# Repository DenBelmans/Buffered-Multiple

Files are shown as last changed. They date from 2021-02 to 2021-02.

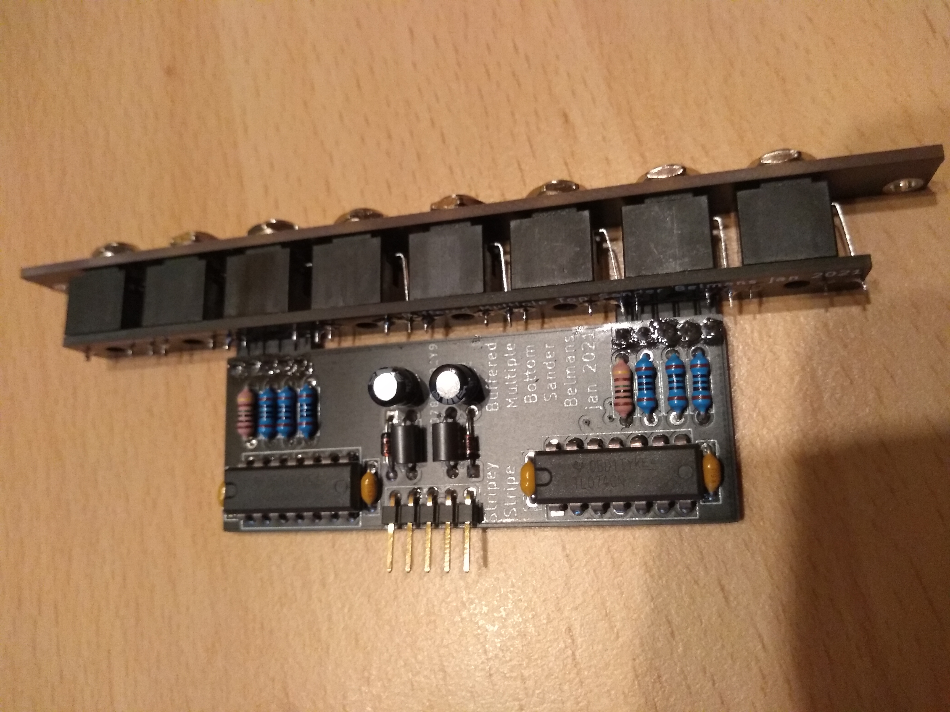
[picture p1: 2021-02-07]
mult2.jpg

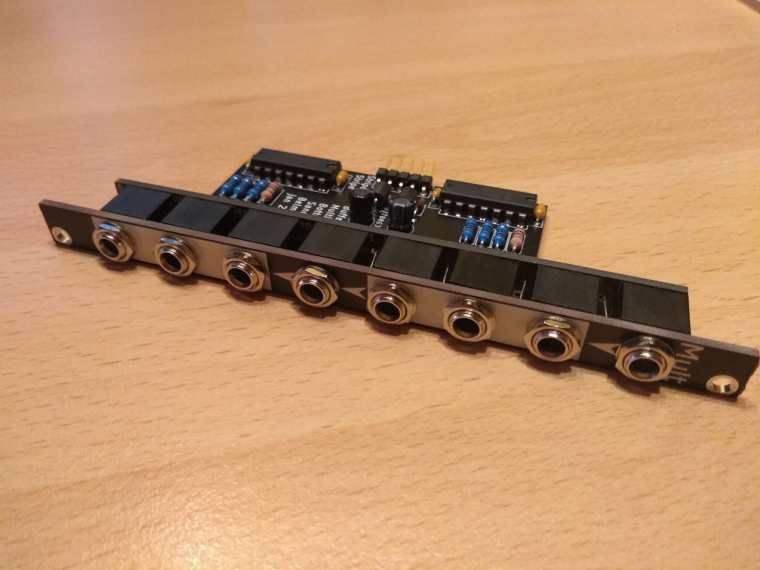
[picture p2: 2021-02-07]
mult1.jpg

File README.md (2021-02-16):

# Buffered-Multiple
A 2HP buffered Multiple in Eurorack format. 2x3 or 1x6 configurations possible.

***** Build Instructions *****

1) Start off by placing the right-angled headers in the PCB that will house the thonkiconns. Place their straight leads through the holes and cut them off flush with the PCB. Take them out again and cut them off a little more so that you can solder them flush to the board without any stubs sticking out. Solder them.
2) Place all thonkiconns on the board, place the front panel on and fasten the nuts. Then flip over the assembly and solder the jacks in place.
3) Take the smaller pcb and solder all resistors, diodes, capacitors and ferrite beads. Make sure you solder the electrolytic capacitors as flush as possible or if you are using caps that are taller than 5mm solder them with their bodies flat on the PCB.
4) Solder the IC's directly to the board. There is no room for sockets!
5) Place the second board on the right angled connectors so that the second board tilted a bit down (towards the side that has no components. Make sure you stay within the 2HP width! Then solder it in place.
6) Solder the 1x5 right angled power connector. I left room for a 2x5 connector but these were a little tall. I used the rowo furthest away from the edge. Solder it so that, when connected, the power connector is within the 2HP width.

That should be all. If you encounter any problems or have questions, feel free to contact me via e-mail: belmansander@gmail.com

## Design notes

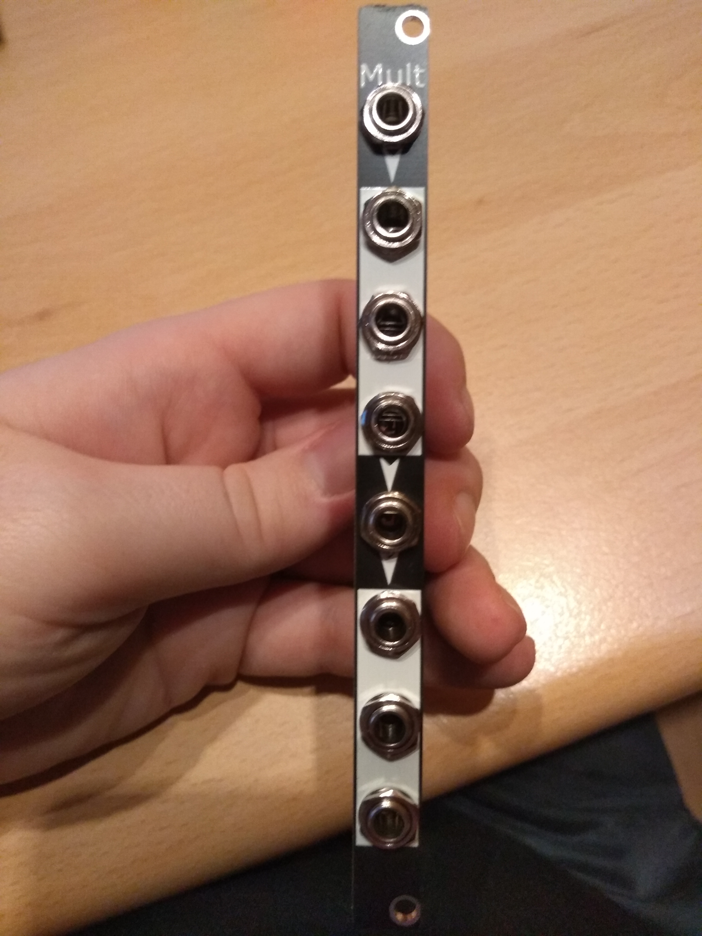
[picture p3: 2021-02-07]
mult3.jpg

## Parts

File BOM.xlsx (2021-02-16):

Buffered Mult BOM
Part | Amount | Mouser number
Thonkiconn jack | 8 |  | Not available at Mouser
1x5 right-angled header | 3 | 649-1012937990501BLF
100 Ohm 1/4W THT resistor | 6 | 603-MFR-25FTF52-100R | 6.3mm length or less
10MOhm 1/4W THT resistor | 2 | 603-HHV-25FR-52-10M | 6.3mm length or less
TL074 op amp | 2 | 595-TL074CN | DIP14
100nF capacitor | 4 | 80-C410C104M5U | any low profile 5mm pitch 100nF cap will do
1N5817 Schottky diode THT | 2 | 583-1N5817-T | 1N4148 diodes work too, though this will result in a maximum output voltage of +/-11V
ferrite bead | 2 | 81-BL01RN1A1F1J | Any ferrite bead. If you don't have these, short both sides
10uF capacitor, low profile | 2 | 667-ECE-A1VKS100I | If you don't have low profile caps, lay flat on the board.

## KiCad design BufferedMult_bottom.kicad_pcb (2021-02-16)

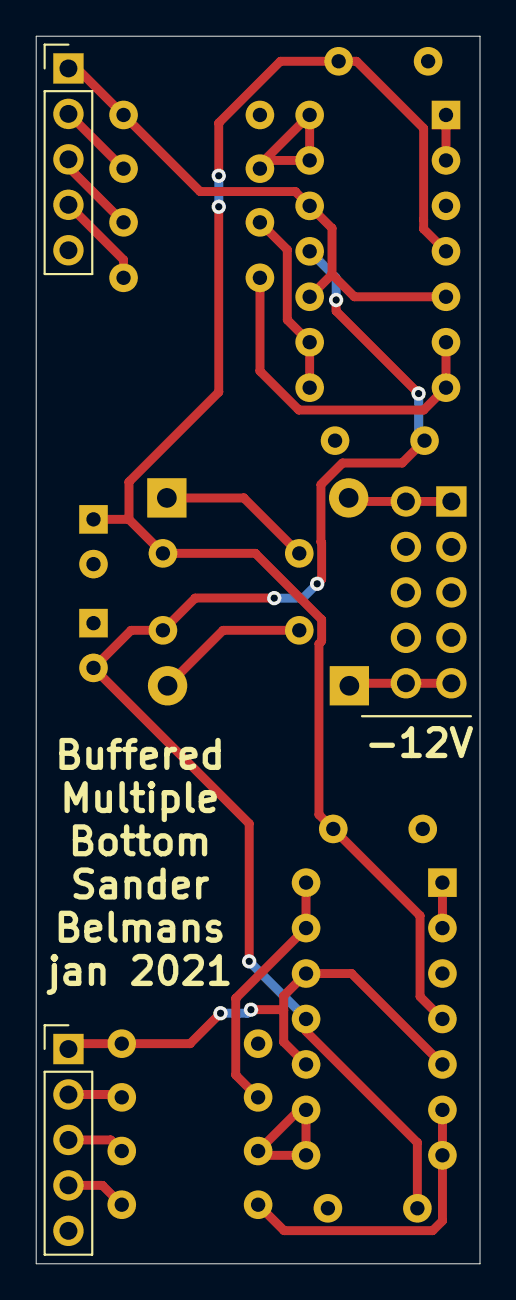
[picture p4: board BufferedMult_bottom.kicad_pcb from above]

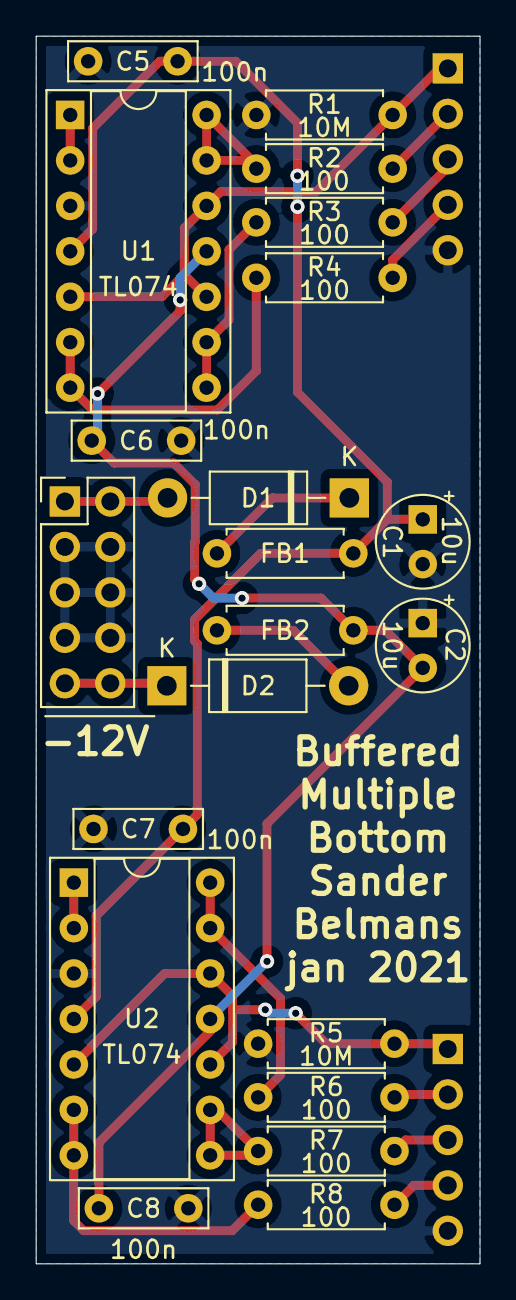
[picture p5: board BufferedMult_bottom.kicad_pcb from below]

Board: 2 copper layers, 24.8 x 68.6 mm, 23 parts (21 on the bottom side), 23 nets.

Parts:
C1, C2: 10u; CP_Radial_Tantal_D5.0mm_P2.50mm
C5, C6, C7, C8: 100n; C_Rect_L7.0mm_W2.0mm_P5.00mm
D1, D2: 1N5817; D_DO-41_SOD81_P10.16mm_Horizontal
FB1, FB2: Ferrite_Bead; R_Axial_DIN0207_L6.3mm_D2.5mm_P7.62mm_Horizontal
J1, J2: Conn_01x05_Male; PinHeader_1x05_P2.54mm_Vertical
J3: Conn_02x05_Odd_Even; PinHeader_2x05_P2.54mm_Vertical
R1, R5: 10M; R_Axial_DIN0207_L6.3mm_D2.5mm_P7.62mm_Horizontal
R2, R3, R4, R6, R7, R8: 100; R_Axial_DIN0207_L6.3mm_D2.5mm_P7.62mm_Horizontal
U1, U2: TL074; DIP-14_W7.62mm_Socket

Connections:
+12V: C1.1, C5.1, C7.1, FB1.2, U1.4, U2.4
-12V: C2.2, C6.2, C8.2, FB2.2, U1.11, U2.11
GND: C1.2, C2.1, C5.2, C6.1, C7.2, C8.1, J1.5, J2.5, J3.3, J3.4, J3.5, J3.6, J3.7, J3.8, R1.1, R5.1, U1.3, U2.3
unnamed: D1.1, FB1.1
unnamed: D1.2, J3.1, J3.2
unnamed: D2.1, J3.9, J3.10
unnamed: D2.2, FB2.1
unnamed: J1.1, R1.2, U1.5, U1.10, U1.12
unnamed: J1.2, R2.2
unnamed: J1.3, R3.2
unnamed: J1.4, R4.2
unnamed: J2.1, R5.2, U2.5, U2.10, U2.12
unnamed: J2.2, R6.2
unnamed: J2.3, R7.2
unnamed: J2.4, R8.2
unnamed: R2.1, U1.13, U1.14
unnamed: R3.1, U1.8, U1.9
unnamed: R4.1, U1.6, U1.7
unnamed: R6.1, U2.13, U2.14
unnamed: R7.1, U2.8, U2.9
unnamed: R8.1, U2.6, U2.7
unnamed: U1.1, U1.2
unnamed: U2.1, U2.2

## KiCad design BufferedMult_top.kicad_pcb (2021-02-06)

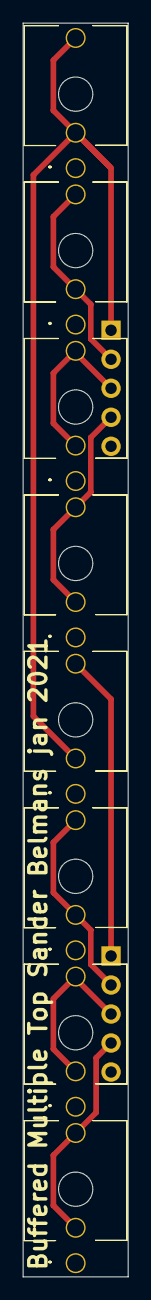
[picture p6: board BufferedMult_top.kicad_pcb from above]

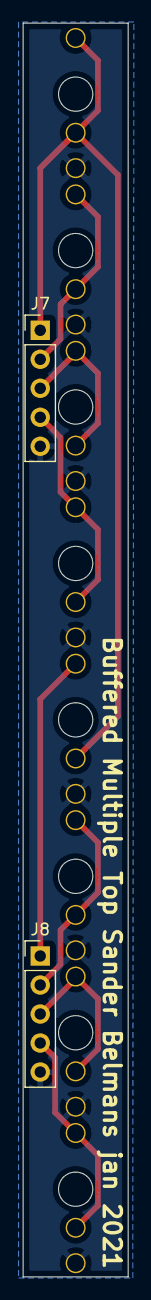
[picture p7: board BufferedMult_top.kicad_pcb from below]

Board: 2 copper layers, 9.2 x 109.8 mm, 10 parts (2 on the bottom side), 9 nets.

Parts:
INA1: AudioJack3; Thonkiconn
INB1: AudioJack3; Thonkiconn
J1, J2, J3, J4, J5, J6: AudioJack3; Thonkiconn
J7, J8: Conn_01x05_Male; PinHeader_1x05_P2.54mm_Vertical

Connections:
GND: INA1.S, INB1.S, J1.S, J2.S, J3.S, J4.S, J5.S, J6.S, J7.5, J8.5
unnamed: INA1.R, INA1.T, INB1.R, J7.1
unnamed: INB1.T, J8.1
unnamed: J1.R, J1.T, J7.2
unnamed: J2.R, J2.T, J7.3
unnamed: J3.R, J3.T, J7.4
unnamed: J4.R, J4.T, J8.2
unnamed: J5.R, J5.T, J8.3
unnamed: J6.R, J6.T, J8.4
